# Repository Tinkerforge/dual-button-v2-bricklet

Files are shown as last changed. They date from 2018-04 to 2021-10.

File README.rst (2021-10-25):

Dual Button Bricklet 2.0
========================

This repository contains the firmware source code and the hardware design
files. The documentation generator configs can be found at
https://github.com/Tinkerforge/generators

Repository Content
------------------

software/:
 * examples/: Examples for all supported languages
 * build/: Compiled files
 * src/: Source code of firmware
 * Makefile: Makefile to build project

hardware/:
 * Contains KiCad project files and additionally schematics as PDF

datasheets/:
 * Contains datasheets for sensors and complex ICs that are used

Hardware
--------

The hardware is designed with the open source EDA Suite KiCad
(http://www.kicad.org). Before you are able to open the files,
you have to install the Tinkerforge kicad-libraries
(https://github.com/Tinkerforge/kicad-libraries). You can either clone
them directly in hardware/ or clone them in a separate folder and
symlink them into hardware/
(ln -s kicad_path/kicad-libraries project_path/hardware). After that you
can open the .pro file in hardware/ with KiCad and from there view and
modify the schematics and the PCB layout.

Software
--------

If you want to do your own Brick/Bricklet firmware development we highly
recommend that you use our build environment setup script and read the
tutorial (https://www.tinkerforge.com/en/doc/Tutorials/Tutorial_Build_Environment/Tutorial.html).

To compile the C code we recommend you to install the newest GNU Arm Embedded
Toolchain (https://launchpad.net/gcc-arm-embedded/+download).
You also need to install bricklib2 (https://github.com/Tinkerforge/bricklib2).

You can either clone it directly in software/src/ or clone it in a
separate folder and symlink it into software/src/
(ln -s bricklib_path/bricklib2 project_path/software/src/). Finally make sure to
have CMake installed (http://www.cmake.org/cmake/resources/software.html).

After that you can build the firmware by invoking make in software/.
The firmware (.zbin) can then be found in software/build/ and uploaded
with brickv (click button "Flashing" on start screen).

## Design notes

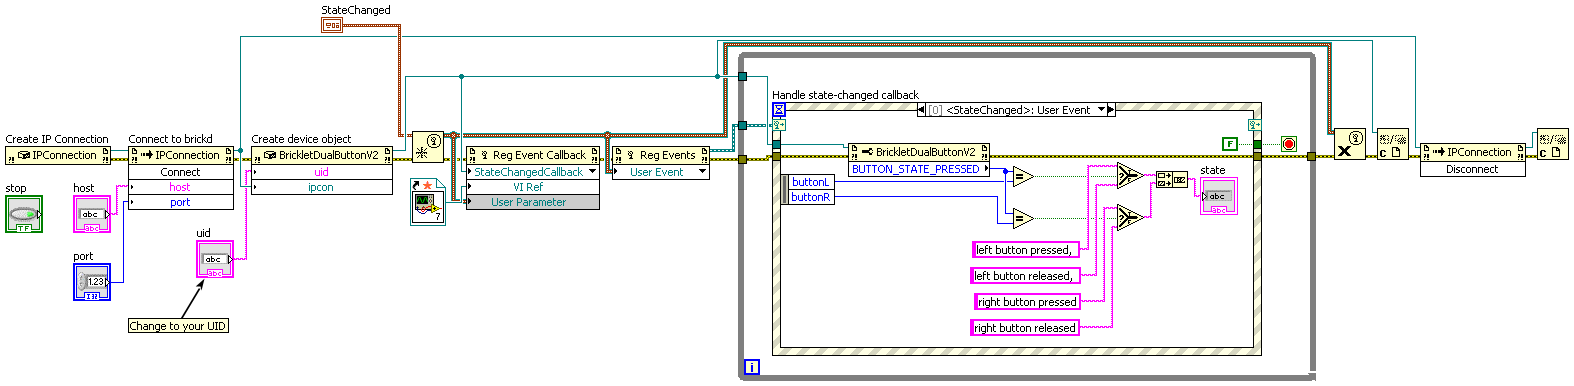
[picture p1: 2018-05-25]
software/examples/labview/Example Callback.vi.png

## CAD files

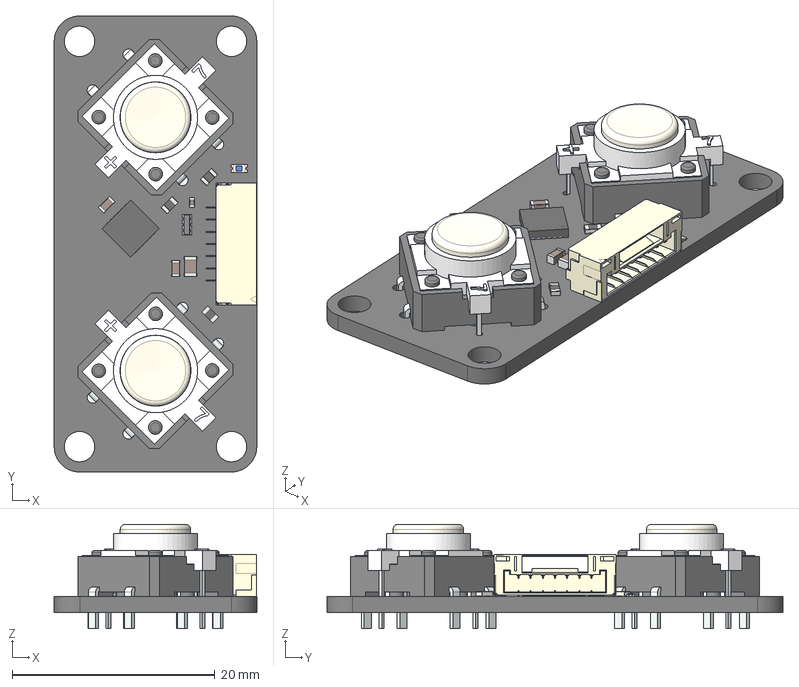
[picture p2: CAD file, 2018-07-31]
hardware/dual-button-v2.step
20.0 x 45.0 x 10.3 mm
Pcb
TACT_SWITCH_12mm_
D_0603_blue_
BrickletConn_7pin_
R_0603_
QFN-24_4x4mm_Pitch0.5mm_
C_0603_
C_0603_001
C_0805_
R_0603_001
R_0603_002
C_0402_
TACT_SWITCH_12mm_001

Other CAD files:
hardware/dual-button-v2.FCStd

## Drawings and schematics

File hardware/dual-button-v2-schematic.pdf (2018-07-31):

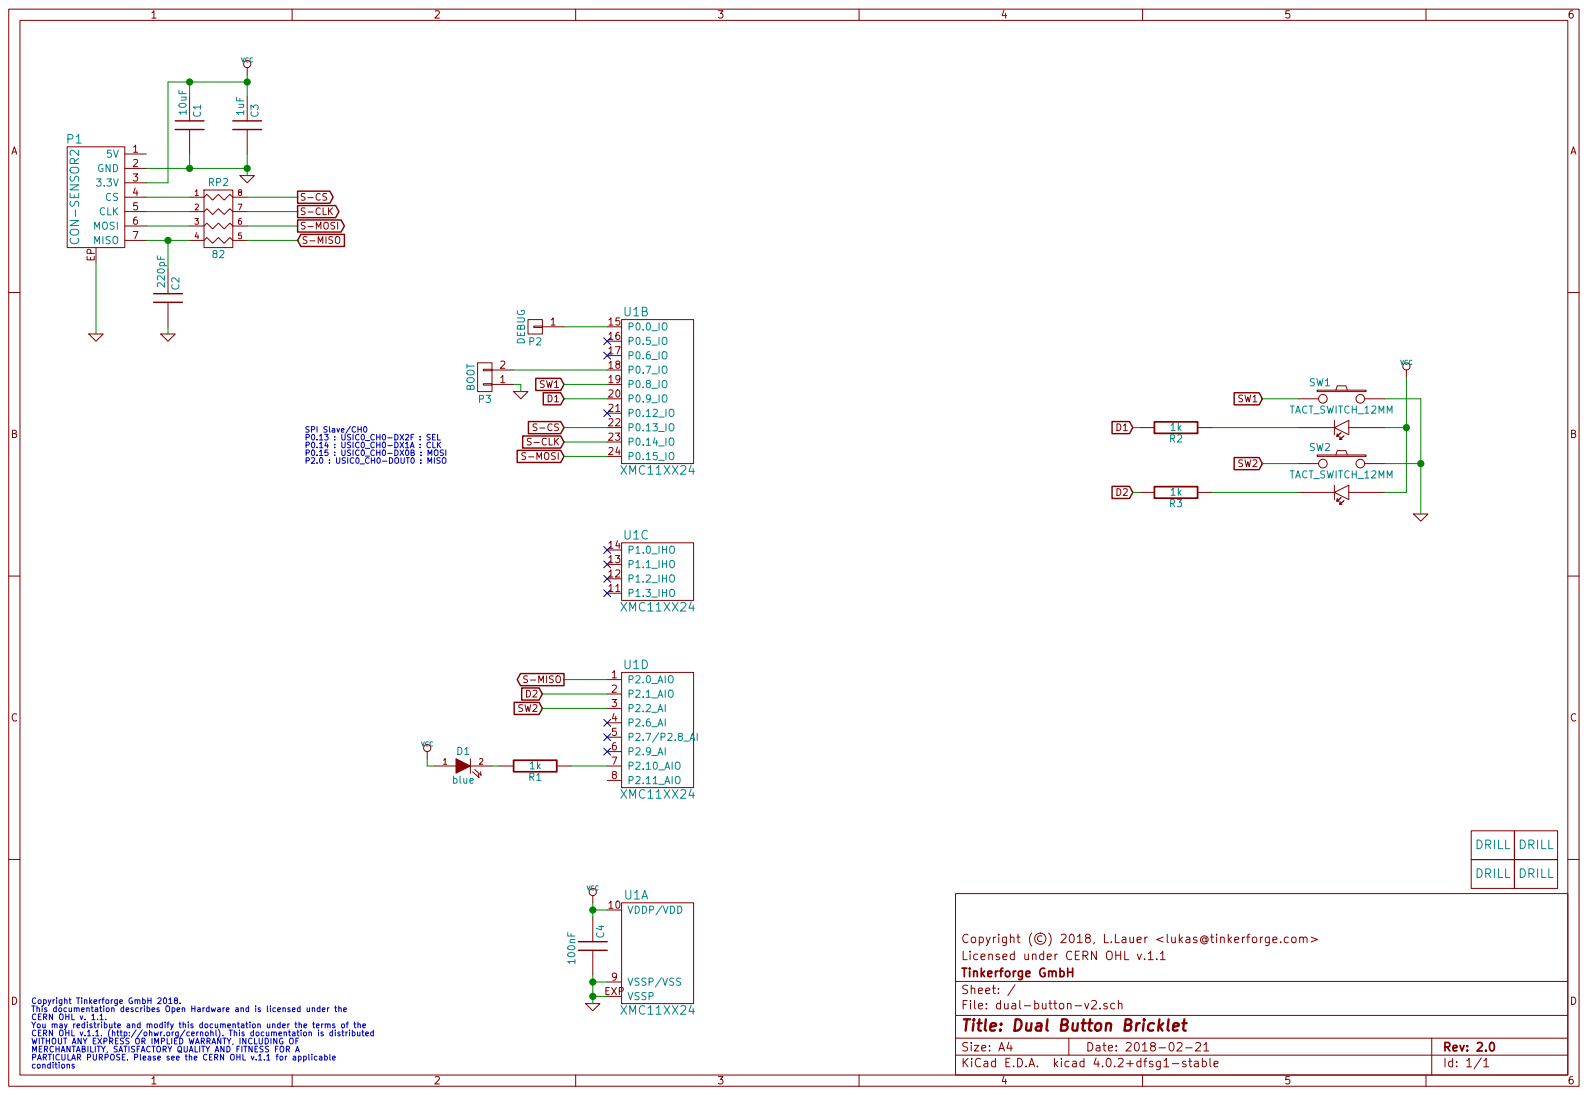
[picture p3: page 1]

SPI Slave/CH0 P0.13 : USIC0_CH0-DX2F : SEL P0.14 : USIC0_CH0-DX1A : CLK

DRILL | DRILL

Licensed under CERN OHL v.1.1 Copyright (©) 2018, L.Lauer <lukas@tinkerforge.com>

Id: 1/1 Title: Dual Button Bricklet File: dual-button-v2.sch Sheet: / Tinkerforge GmbH

Copyright Tinkerforge GmbH 2018. This documentation describes Open Hardware and is licensed under the CERN OHL v. 1.1. You may redistribute and modify this documentation under the terms of the CERN OHL v.1.1. (http://ohwr.org/cernohl). This documentation is distributed WITHOUT ANY EXPRESS OR IMPLIED WARRANTY, INCLUDING OF MERCHANTABILITY, SATISFACTORY QUALITY AND FITNESS FOR A

PARTICULAR PURPOSE. Please see the CERN OHL v.1.1 for applicable

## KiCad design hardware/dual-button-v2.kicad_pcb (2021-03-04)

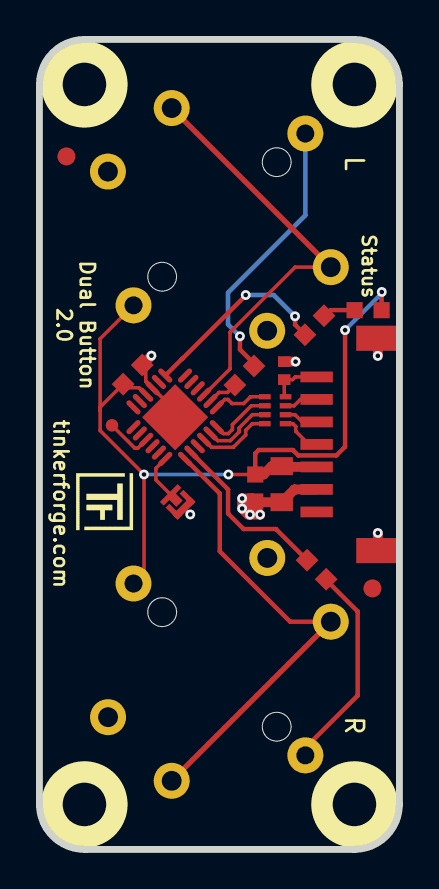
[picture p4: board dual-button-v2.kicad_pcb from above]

Board: 2 copper layers, 20.0 x 45.0 mm, 24 parts (0 on the bottom side), 20 nets.

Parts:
C1: 10uF; C0805
C2: 220pF; C0402F
C3: 1uF; C0603F
C4: 100nF; C0603F
D1: blue; D0603F
Fiducial_Mark: VAL**; Fiducial_Mark
Fiducial_Mark#2: VAL**; Fiducial_Mark
P1: CON-SENSOR2
P2: DEBUG; DEBUG_PAD
P3: BOOT; SolderJumper
R1, R2, R3: 1k; R0603F
RP2: 82; 4X0402
Ref**: Val**; Logo_31x31
SW1, SW2: TACT_SWITCH_12MM; TACT_SWITCH_12mm
U1: XMC1100; QFN24-4x4mm-0.5mm
U2, U3, U4, U5: DRILL; DRILL_NP
VAL: CE_5mm
VAL#2: WEEE_7mm

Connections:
D1: R2.2, U1.20
D2: R3.2, U1.2
GND: C1.1, C2.1, C3.1, C4.1, P1.2, P1.EP, P3.1, SW1.3, SW2.3, U1.9, U1.EXP
unnamed: C2.2, P1.7, RP2.4
unnamed: D1.2, R1.2
unnamed: P1.4, RP2.1
unnamed: P1.5, RP2.2
unnamed: P1.6, RP2.3
unnamed: P2.1, U1.15
unnamed: P3.2, U1.18
unnamed: R1.1, U1.7
unnamed: R2.1, SW1.2
unnamed: R3.1, SW2.2
S-CLK: RP2.7, U1.23
S-CS: RP2.8, U1.22
S-MISO: RP2.5, U1.1
S-MOSI: RP2.6, U1.24
SW1: SW1.4, U1.19
SW2: SW2.4, U1.3
VCC: C1.2, C3.2, C4.2, D1.1, P1.3, SW1.1, SW2.1, U1.10

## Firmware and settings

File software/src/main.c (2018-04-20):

/* dual-button-v2-bricklet
 * Copyright (C) 2018 Olaf Lüke <olaf@tinkerforge.com>
 *
 * main.c: Initialization for Dual Button V2 Bricklet
 *
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
 * You should have received a copy of the GNU Lesser General Public
 * License along with this library; if not, write to the
 * Free Software Foundation, Inc., 59 Temple Place - Suite 330,
 * Boston, MA 02111-1307, USA.
 */

#include <stdio.h>
#include <stdbool.h>

#include "configs/config.h"

#include "bricklib2/bootloader/bootloader.h"
#include "bricklib2/hal/system_timer/system_timer.h"
#include "bricklib2/logging/logging.h"
#include "communication.h"

int main(void) {
	logging_init();
	logd("Start Dual Button V2 Bricklet\n\r");

	communication_init();

	while(true) {
		bootloader_tick();
		communication_tick();
	}
}

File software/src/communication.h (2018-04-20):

/* dual-button-v2-bricklet
 * Copyright (C) 2018 Olaf Lüke <olaf@tinkerforge.com>
 *
 * communication.h: TFP protocol message handling
 *
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
 * You should have received a copy of the GNU Lesser General Public
 * License along with this library; if not, write to the
 * Free Software Foundation, Inc., 59 Temple Place - Suite 330,
 * Boston, MA 02111-1307, USA.
 */

#ifndef COMMUNICATION_H
#define COMMUNICATION_H

#include <stdint.h>
#include <stdbool.h>

#include "bricklib2/protocols/tfp/tfp.h"
#include "bricklib2/bootloader/bootloader.h"

// Default functions
BootloaderHandleMessageResponse handle_message(const void *data, void *response);
void communication_tick(void);
void communication_init(void);

// Constants
#define DUAL_BUTTON_V2_LED_STATE_AUTO_TOGGLE_ON 0
#define DUAL_BUTTON_V2_LED_STATE_AUTO_TOGGLE_OFF 1
#define DUAL_BUTTON_V2_LED_STATE_ON 2
#define DUAL_BUTTON_V2_LED_STATE_OFF 3

#define DUAL_BUTTON_V2_BUTTON_STATE_PRESSED 0
#define DUAL_BUTTON_V2_BUTTON_STATE_RELEASED 1

#define DUAL_BUTTON_V2_LED_LEFT 0
#define DUAL_BUTTON_V2_LED_RIGHT 1

#define DUAL_BUTTON_V2_BOOTLOADER_MODE_BOOTLOADER 0
#define DUAL_BUTTON_V2_BOOTLOADER_MODE_FIRMWARE 1
#define DUAL_BUTTON_V2_BOOTLOADER_MODE_BOOTLOADER_WAIT_FOR_REBOOT 2
#define DUAL_BUTTON_V2_BOOTLOADER_MODE_FIRMWARE_WAIT_FOR_REBOOT 3
#define DUAL_BUTTON_V2_BOOTLOADER_MODE_FIRMWARE_WAIT_FOR_ERASE_AND_REBOOT 4

#define DUAL_BUTTON_V2_BOOTLOADER_STATUS_OK 0
#define DUAL_BUTTON_V2_BOOTLOADER_STATUS_INVALID_MODE 1
#define DUAL_BUTTON_V2_BOOTLOADER_STATUS_NO_CHANGE 2
#define DUAL_BUTTON_V2_BOOTLOADER_STATUS_ENTRY_FUNCTION_NOT_PRESENT 3
#define DUAL_BUTTON_V2_BOOTLOADER_STATUS_DEVICE_IDENTIFIER_INCORRECT 4
#define DUAL_BUTTON_V2_BOOTLOADER_STATUS_CRC_MISMATCH 5

#define DUAL_BUTTON_V2_STATUS_LED_CONFIG_OFF 0
#define DUAL_BUTTON_V2_STATUS_LED_CONFIG_ON 1
#define DUAL_BUTTON_V2_STATUS_LED_CONFIG_SHOW_HEARTBEAT 2
#define DUAL_BUTTON_V2_STATUS_LED_CONFIG_SHOW_STATUS 3

// Function and callback IDs and structs
#define FID_SET_LED_STATE 1
#define FID_GET_LED_STATE 2
#define FID_GET_BUTTON_STATE 3
#define FID_SET_SELECTED_LED_STATE 5
#define FID_SET_STATE_CHANGED_CALLBACK_CONFIGURATION 6
#define FID_GET_STATE_CHANGED_CALLBACK_CONFIGURATION 7

#define FID_CALLBACK_STATE_CHANGED 4

typedef struct {
	TFPMessageHeader header;
	uint8_t led_l;
	uint8_t led_r;
} __attribute__((__packed__)) SetLEDState;

typedef struct {
	TFPMessageHeader header;
} __attribute__((__packed__)) GetLEDState;

typedef struct {
	TFPMessageHeader header;
	uint8_t led_l;
	uint8_t led_r;
} __attribute__((__packed__)) GetLEDState_Response;

typedef struct {
	TFPMessageHeader header;
} __attribute__((__packed__)) GetButtonState;

typedef struct {
	TFPMessageHeader header;
	uint8_t button_l;
	uint8_t button_r;
} __attribute__((__packed__)) GetButtonState_Response;

typedef struct {
	TFPMessageHeader header;
	uint8_t button_l;
	uint8_t button_r;
	uint8_t led_l;
	uint8_t led_r;
} __attribute__((__packed__)) StateChanged_Callback;

typedef struct {
	TFPMessageHeader header;
	uint8_t led;
	uint8_t state;
} __attribute__((__packed__)) SetSelectedLEDState;

typedef struct {
	TFPMessageHeader header;
	bool enabled;
} __attribute__((__packed__)) SetStateChangedCallbackConfiguration;

typedef struct {
	TFPMessageHeader header;
} __attribute__((__packed__)) GetStateChangedCallbackConfiguration;

typedef struct {
	TFPMessageHeader header;
	bool enabled;
} __attribute__((__packed__)) GetStateChangedCallbackConfiguration_Response;


// Function prototypes
BootloaderHandleMessageResponse set_led_state(const SetLEDState *data);
BootloaderHandleMessageResponse get_led_state(const GetLEDState *data, GetLEDState_Response *response);
BootloaderHandleMessageResponse get_button_state(const GetButtonState *data, GetButtonState_Response *response);
BootloaderHandleMessageResponse set_selected_led_state(const SetSelectedLEDState *data);
BootloaderHandleMessageResponse set_state_changed_callback_configuration(const SetStateChangedCallbackConfiguration *data);
BootloaderHandleMessageResponse get_state_changed_callback_configuration(const GetStateChangedCallbackConfiguration *data, GetStateChangedCallbackConfiguration_Response *response);

// Callbacks
bool handle_state_changed_callback(void);

#define COMMUNICATION_CALLBACK_TICK_WAIT_MS 1
#define COMMUNICATION_CALLBACK_HANDLER_NUM 1
#define COMMUNICATION_CALLBACK_LIST_INIT \
	handle_state_changed_callback, \


#endif

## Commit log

2018-02-21 Add schematic
    [dual_button.sch]
2018-02-21 Add layout
    [dual_button.kicad_pcb]
2018-03-15 change drilling holes to new standard
    [dual_button.kicad_pcb]
2018-04-20 Add auto-generated stub implementation
    [cmake_config_custom.txt]
2018-04-20 Set correct pins for leds/boot pad/debug
    [config_custom_bootloader.h, config_custom_bootstrapper.h]
2018-04-20 Implement LED/button api and driver
2018-05-11 Rename files
    [dual-button-v2.kicad_pcb, dual-button-v2.sch]
2018-05-28 examples: Unify constant printing style
2018-06-06 fix logo position, fix origin
    [dual-button-v2.kicad_pcb]
2018-06-07 fix bottom copper outline
    [dual-button-v2.kicad_pcb]
2018-06-18 Change capacitor footprint(s) to C0402F
    [dual-button-v2.kicad_pcb, dual-button-v2.sch]
2018-06-22 Add 3d information (final)
    [dual-button-v2.kicad_pcb]
2018-06-22 Add 3d model (*.step & *.FCStd)
    [dual-button-v2.FCStd, dual-button-v2.step]
2018-07-17 specify processor
    [dual-button-v2.kicad_pcb, dual-button-v2.sch]
2018-07-31 Add 3d model (*.FCStd & *.step)
    [dual-button-v2.FCStd, dual-button-v2.step]
2018-07-31 Add PDF schematic
2019-08-22 c: Adapt to bindings changes
    [example_callback.c]
2020-09-02 uc: Add example driver note.
2021-03-04 increase pad diameter
    [dual-button-v2.kicad_pcb]
2021-10-25 Update KiCad link
    https://www.kicad.org/blog/2021/10/Avoid-links-to-former-kicad-domain/
2022-04-27 uc: Adapt to bindings changes
    [example_callback.c]
